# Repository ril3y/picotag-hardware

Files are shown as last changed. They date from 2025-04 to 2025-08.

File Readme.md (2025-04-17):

# PicoTag – Hardware Overview

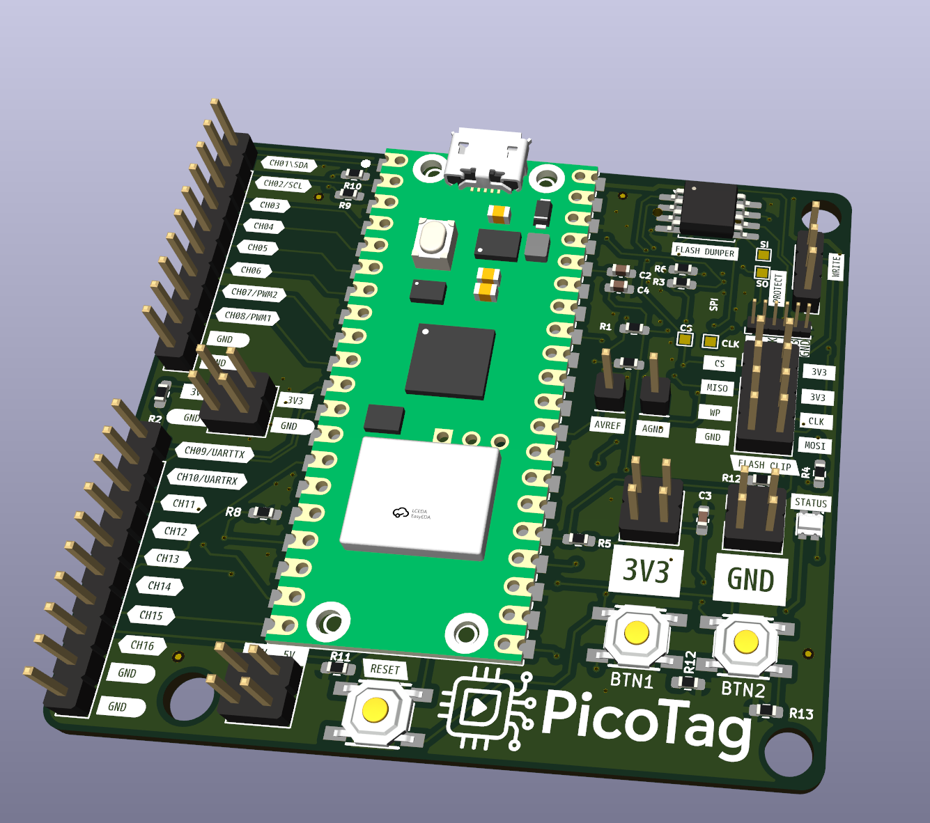
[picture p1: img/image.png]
PicoTag Hardware


**PicoTag** is a compact hardware reverse engineering and interface discovery board powered by the Raspberry Pi Pico W. It is designed for embedded developers and security researchers who need to scan, probe, and interact with unknown hardware interfaces like JTAG, SWD, SPI, and UART. The board routes 16 GPIOs for flexible digital analysis, integrates a flash dumper interface, and supports a built-in terminal experience via USB.

---

## 🧠 Core Features

- **Powered by Raspberry Pi Pico W (RP2040W)**
  - Dual-core ARM Cortex-M0+
  - USB-CDC console for interacting with the onboard terminal (SpicyTerm)
  - Wi-Fi ready for future remote applications

- **Runs PicoTag Terminal**
  - Interactive command-line terminal over USB serial
  - Extensible command modules (JTAG scan, Flash dump, GPIO monitor, etc.)

- **Supports Analog Inputs (3.3V only)**
  - Safely connect analog signals for measurement and analysis

---

## ⚙️ GPIO Scan Interface

- **16 dedicated GPIO channels** labeled `CH01` to `CH16`
  - Direct 3.3 V logic (no level shifting)
  - Clearly labeled edge connector for easy probing
  - CH01/02 double as I2C (SDA/SCL)
  - CH09/10 double as UART (TX/RX)
  - CH07/08 labeled for PWM

- **All GPIOs referenced to 3.3 V domain**
  - Designed for direct connection to 3.3 V targets
  - Ground and 3.3 V rails provided next to scan header for scope or logic analyzer use

---

## 🔌 Flash Dumper Interface

- **Dedicated SPI flash dump section**
  - Labeled `FLASH DUMPER` with headers for:
    - `CS`, `CLK`, `MISO`, `MOSI`, `WP`, `HOLD`
  - Designed for quick clip-to-dump workflows using SOIC-8 flash clips
  - Jumper-selectable voltage (3.3 V-only)
  - Status LED indicates active operations

---

## 🧠 Control & I/O

- **Two tactile buttons**: `BTN1` and `BTN2`
  - Used for scan triggers, reset functions, or user-defined inputs

- **RESET button** for the Pico W

- **Visuals and labeling**
  - High-quality silkscreen labels for every interface
  - Clean corner mounting holes and rounded PCB edges

---

## 🔋 Power Supply

- **USB-powered (5 V input via Pico W USB)**
- Onboard LDO provides 3.3 V (shared with all logic and headers)
- 3.3 V and GND pins broken out at multiple locations

---

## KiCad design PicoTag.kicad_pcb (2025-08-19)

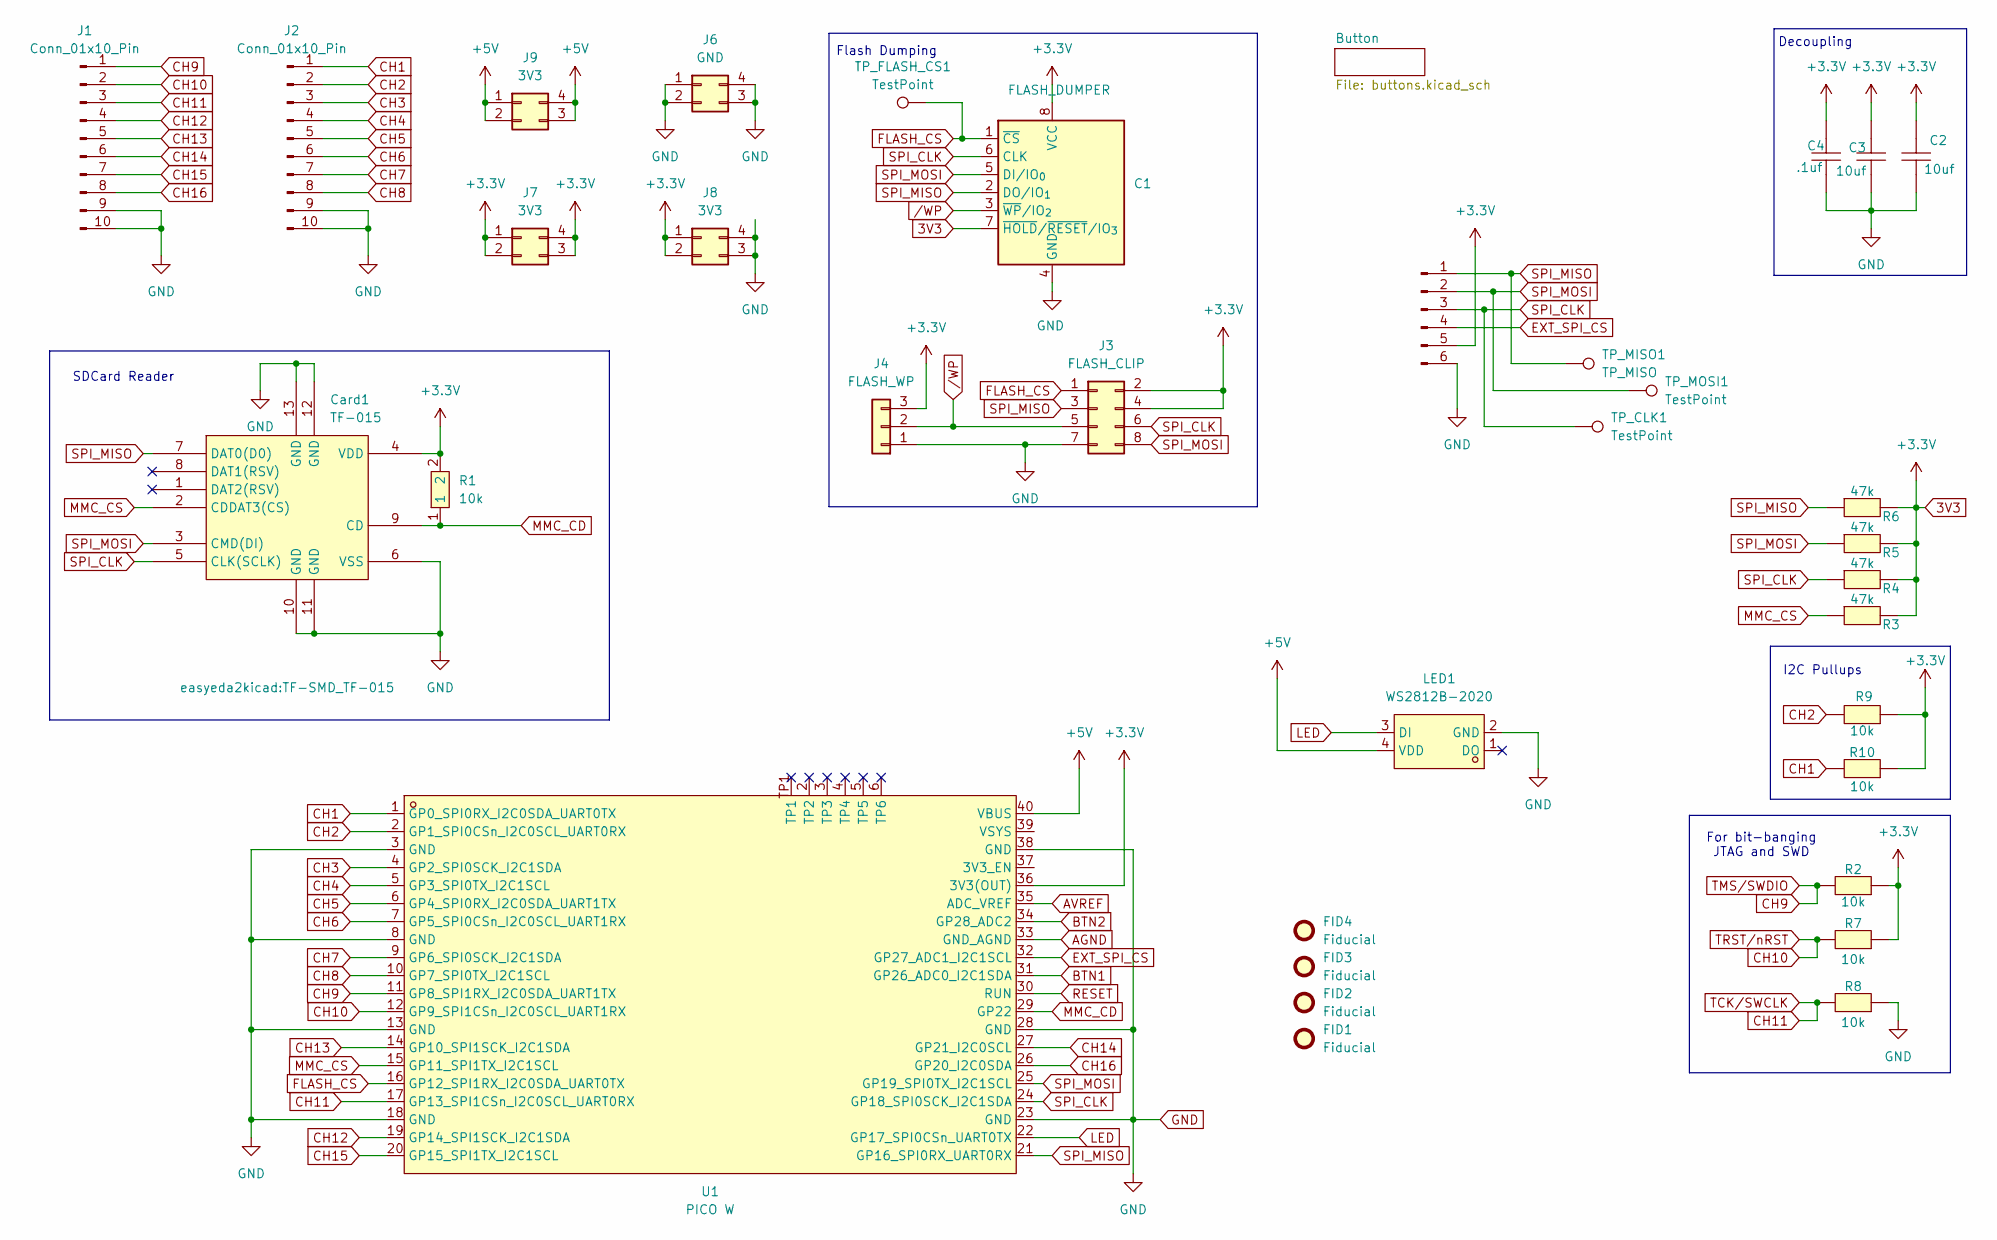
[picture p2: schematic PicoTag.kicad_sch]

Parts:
C1: FLASH_DUMPER; SOIC-8_5.3x5.3mm_P1.27mm flash dumper
C2, C3: 10uf; C_0603_1608Metric_Pad1.08x0.95mm_HandSolder; LCSC Part C1691
C4: .1uf; C_0603_1608Metric_Pad1.08x0.95mm_HandSolder; LCSC Part C1591
Card1: TF-015; TF-SMD_TF-015; LCSC Part C113206
FID1, FID2, FID3, FID4: Fiducial; Fiducial_0.5mm_Mask1mm
J1, J2: Conn_01x10_Pin; PinHeader_1x10_P2.54mm_Vertical
J3: FLASH_CLIP; PinHeader_2x04_P2.54mm_Vertical
J4: FLASH_WP; PinHeader_1x03_P2.54mm_Vertical
J6: GND; PinHeader_2x02_P2.54mm_Vertical
J7, J8, J9: 3V3; PinHeader_2x02_P2.54mm_Vertical
J11: Conn_01x06_Pin; PinHeader_1x06_P1.00mm_Vertical
LED1: WS2812B-2020; LED-SMD_4P-L2.0-W2.0-TL_WS2812B-2020; LCSC Part C965555
R1, R2, R7, R8, R9, R10: 10k; R_0603_1608Metric_Pad0.98x0.95mm_HandSolder; LCSC Part C2930027
R3, R4, R5, R6: 47k; R_0603_1608Metric_Pad0.98x0.95mm_HandSolder; LCSC Part C3016374
TP_CLK1: TestPoint; TestPoint_Pad_1.0x1.0mm
TP_FLASH_CS1: TestPoint; TestPoint_Pad_1.0x1.0mm
TP_MISO1: TP_MISO; TestPoint_Pad_1.0x1.0mm
TP_MOSI1: TestPoint; TestPoint_Pad_1.0x1.0mm
U1: PICO W; COMM-SMD_L51.0-W21.0-P2.54_PICOW; LCSC Part C7203003

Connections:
3V3: C1.7 (~HOLD/~RESET/IO_{3}), C1.8 (VCC), C2.2, C3.2, C4.2, Card1.4 (VDD), J3.2, J3.4, J4.3, J7.1, J7.2, J7.3, J7.4, J8.1, J8.2, J11.5, R1.2, R2.1, R3.2, R4.2, R5.2, R6.2, R7.1, R9.1, R10.1, U1.36 (3V3(OUT)); also elsewhere on the board
+5V: J9.1, J9.2, J9.3, J9.4, LED1.4 (VDD), U1.40 (VBUS)
AGND: U1.33 (GND_AGND)
AVREF: U1.35 (ADC_VREF)
BTN1: U1.31 (GP26_ADC0_I2C1SDA); also elsewhere on the board
BTN2: U1.34 (GP28_ADC2); also elsewhere on the board
CH1: J2.1, R10.2, U1.1 (GP0_SPI0RX_I2C0SDA_UART0TX)
CH2: J2.2, R9.2, U1.2 (GP1_SPI0CSn_I2C0SCL_UART0RX)
CH3: J2.3, U1.4 (GP2_SPI0SCK_I2C1SDA)
CH4: J2.4, U1.5 (GP3_SPI0TX_I2C1SCL)
CH5: J2.5, U1.6 (GP4_SPI0RX_I2C0SDA_UART1TX)
CH6: J2.6, U1.7 (GP5_SPI0CSn_I2C0SCL_UART1RX)
CH7: J2.7, U1.9 (GP6_SPI0SCK_I2C1SDA)
CH8: J2.8, U1.10 (GP7_SPI0TX_I2C1SCL)
CH9: J1.1, R2.2, U1.11 (GP8_SPI1RX_I2C0SDA_UART1TX)
CH10: J1.2, R7.2, U1.12 (GP9_SPI1CSn_I2C0SCL_UART1RX)
CH11: J1.3, R8.2, U1.17 (GP13_SPI1CSn_I2C0SCL_UART0RX)
CH12: J1.4, U1.19 (GP14_SPI1SCK_I2C1SDA)
CH13: J1.5, U1.14 (GP10_SPI1SCK_I2C1SDA)
CH14: J1.6, U1.27 (GP21_I2C0SCL)
CH15: J1.7, U1.20 (GP15_SPI1TX_I2C1SCL)
CH16: J1.8, U1.26 (GP20_I2C0SDA)
EXT_SPI_CS: J11.4, U1.32 (GP27_ADC1_I2C1SCL)
FLASH_CS: C1.1 (~CS), J3.1, TP_FLASH_CS1.1, U1.16 (GP12_SPI1RX_I2C0SDA_UART0TX)
GND: C1.4 (GND), C2.1, C3.1, C4.1, Card1.6 (VSS), Card1.10 (GND), Card1.11 (GND), Card1.12 (GND), Card1.13 (GND), J1.9, J1.10, J2.9, J2.10, J3.7, J4.1, J6.1, J6.2, J6.3, J6.4, J8.3, J8.4, J11.6, LED1.2 (GND), R8.1, U1.3 (GND), U1.8 (GND), U1.13 (GND), U1.18 (GND), U1.23 (GND), U1.28 (GND), U1.38 (GND); also elsewhere on the board
LED: LED1.3 (DI), U1.22 (GP17_SPI0CSn_UART0TX)
MMC_CD: Card1.9 (CD), R1.1, U1.29 (GP22)
MMC_CS: Card1.2 (CDDAT3(CS)), R3.1, U1.15 (GP11_SPI1TX_I2C1SCL)
RESET: U1.30 (RUN); also elsewhere on the board
SPI_CLK: C1.6 (CLK), Card1.5 (CLK(SCLK)), J3.6, J11.3, R4.1, TP_CLK1.1, U1.24 (GP18_SPI0SCK_I2C1SDA)
SPI_MISO: C1.2 (DO/IO_{1}), Card1.7 (DAT0(D0)), J3.3, J11.1, R6.1, TP_MISO1.1, U1.21 (GP16_SPI0RX_UART0RX)
SPI_MOSI: C1.5 (DI/IO_{0}), Card1.3 (CMD(DI)), J3.8, J11.2, R5.1, TP_MOSI1.1, U1.25 (GP19_SPI0TX_I2C1SCL)
/WP: C1.3 (~WP/IO_{2}), J3.5, J4.2

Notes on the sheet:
Flash Dumping
SDCard Reader
For bit-banging JTAG and SWD
Decoupling
I2C Pullups

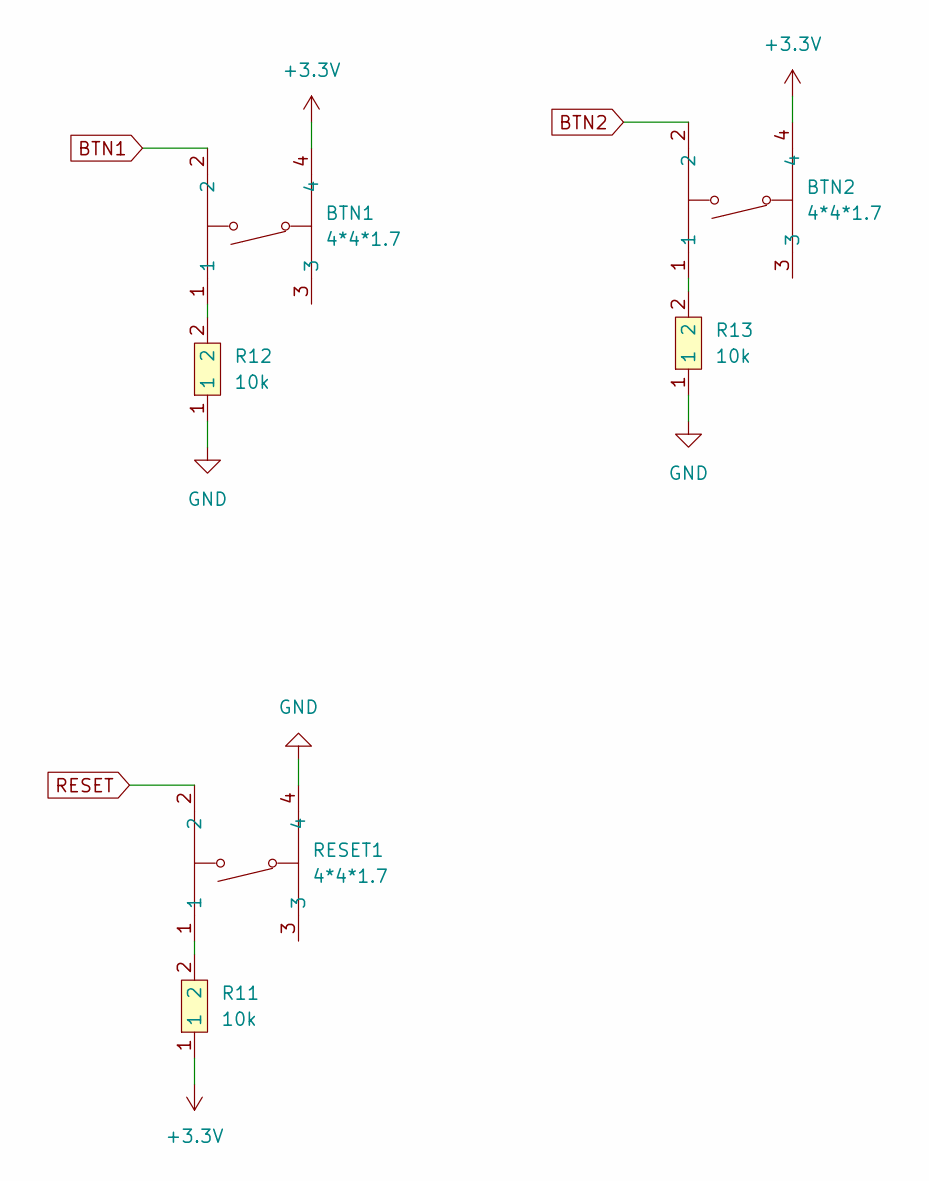
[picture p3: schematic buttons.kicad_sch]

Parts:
BTN1, BTN2: 4*4*1.7; SW-SMD_4P-L5.2-W5.2-P3.70-LS6.5; LCSC Part C10852
R11, R12, R13: 10k; R_0603_1608Metric_Pad0.98x0.95mm_HandSolder; LCSC Part C2930027
RESET1: 4*4*1.7; SW-SMD_4P-L5.2-W5.2-P3.70-LS6.5; LCSC Part C10852

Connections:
3V3: BTN1.4, BTN2.4, R11.1; also elsewhere on the board
BTN1: BTN1.2; also elsewhere on the board
BTN2: BTN2.2; also elsewhere on the board
GND: R12.1, R13.1, RESET1.4; also elsewhere on the board
unnamed: BTN1.1, R12.2
unnamed: BTN2.1, R13.2
unnamed: R11.2, RESET1.1
RESET: RESET1.2; also elsewhere on the board

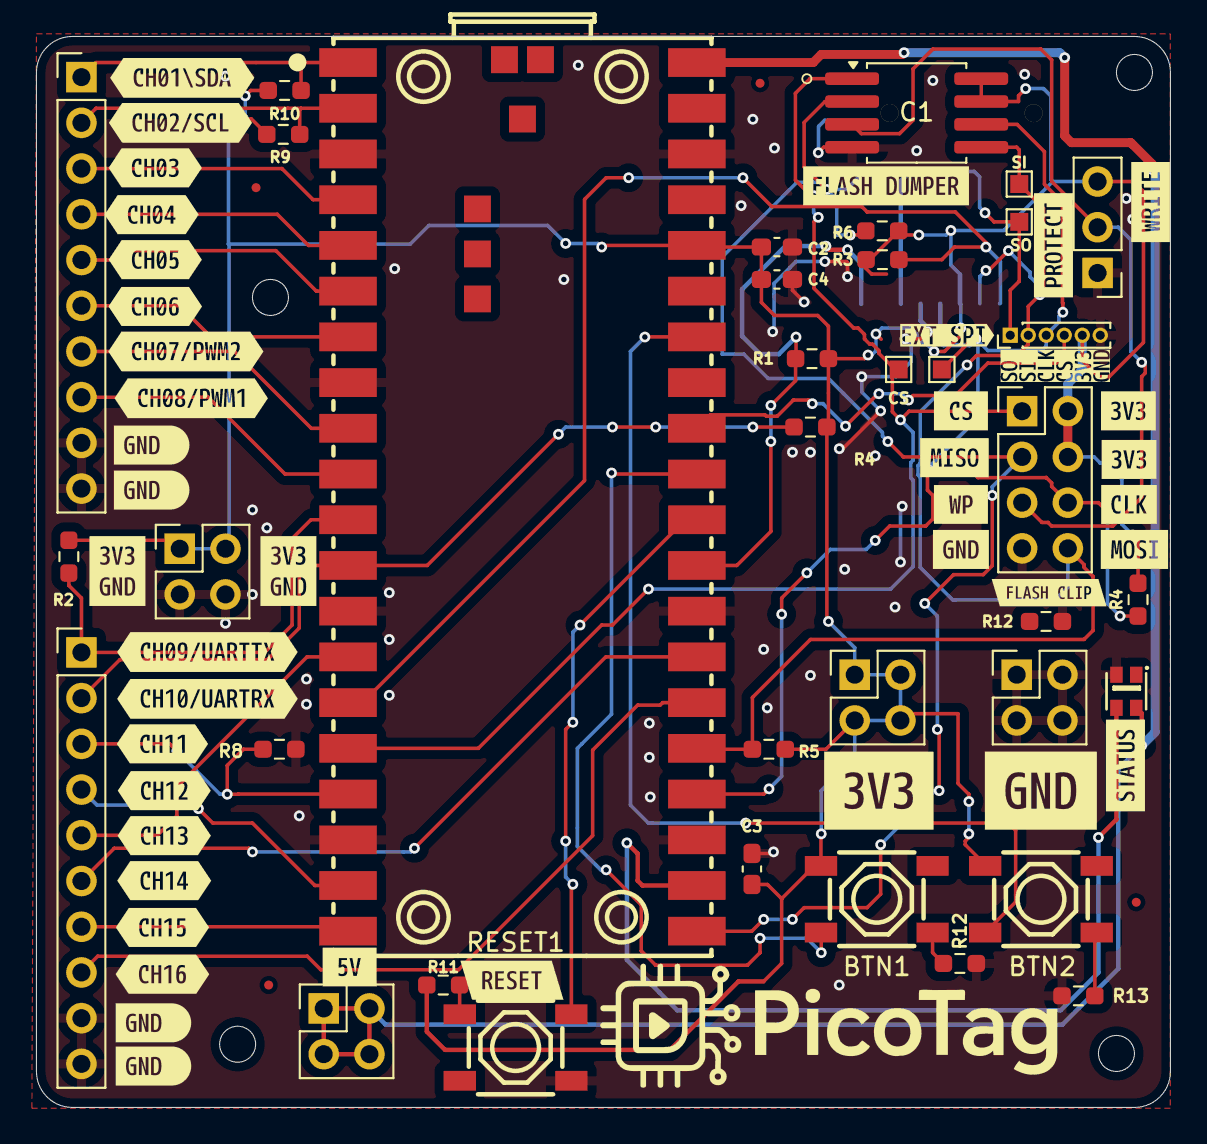
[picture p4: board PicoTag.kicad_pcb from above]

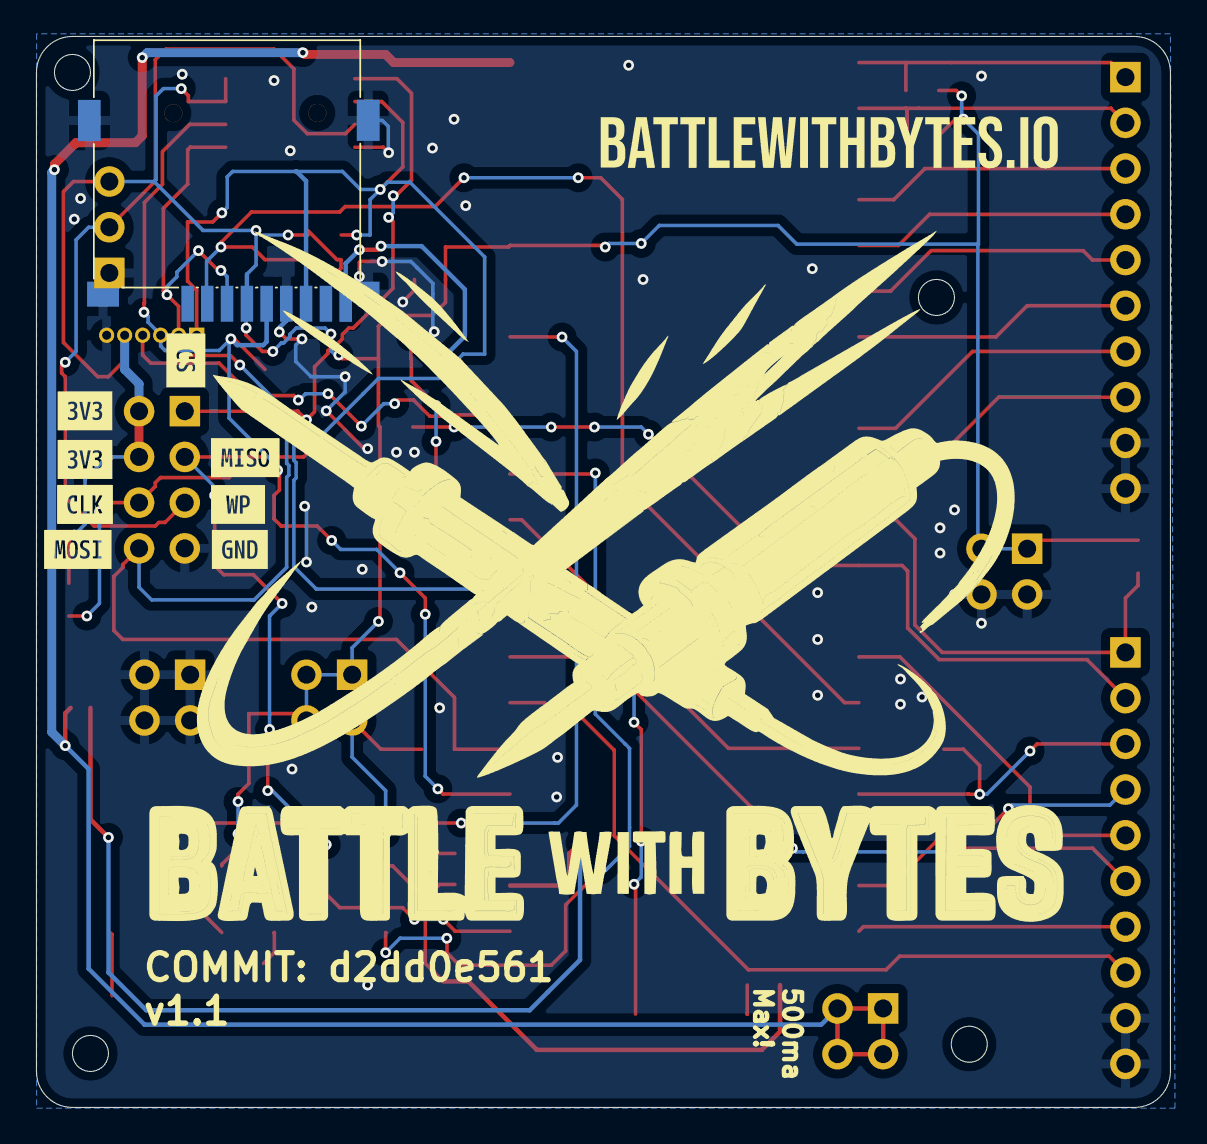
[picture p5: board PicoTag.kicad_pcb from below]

Board: 2 copper layers, 63.0 x 59.5 mm, 90 parts (9 on the bottom side), 34 nets.

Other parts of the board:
R12#2: 10k; R_0603_1608Metric_Pad0.98x0.95mm_HandSolder
kibuzzard-680A2A33: G***; kibuzzard-680A2A33
kibuzzard-680A2B2B: G***; kibuzzard-680A2B2B
kibuzzard-680A2B82: G***; kibuzzard-680A2B82
kibuzzard-680A26BF: G***; kibuzzard-680A26BF
kibuzzard-680A26E6: G***; kibuzzard-680A26E6
kibuzzard-680A26F2: G***; kibuzzard-680A26F2
kibuzzard-680A27E0, kibuzzard-680A27E0#2: G***; kibuzzard-680A27E0
kibuzzard-680A28B1: G***; kibuzzard-680A28B1
kibuzzard-680A28C8: G***; kibuzzard-680A28C8
kibuzzard-680A28D6: G***; kibuzzard-680A28D6
kibuzzard-680A28F0: G***; kibuzzard-680A28F0
kibuzzard-680A29B1: G***; kibuzzard-680A29B1
kibuzzard-680A29B9: G***; kibuzzard-680A29B9
kibuzzard-680A29C1: G***; kibuzzard-680A29C1
kibuzzard-680A29CB: G***; kibuzzard-680A29CB
kibuzzard-680A29D5: G***; kibuzzard-680A29D5
kibuzzard-680A29E5: G***; kibuzzard-680A29E5
kibuzzard-680A271C: G***; kibuzzard-680A271C
kibuzzard-680A273A: G***; kibuzzard-680A273A
kibuzzard-680A275A: G***; kibuzzard-680A275A
kibuzzard-680A280E: G***; kibuzzard-680A280E
kibuzzard-680A281D: G***; kibuzzard-680A281D
kibuzzard-680A282F, kibuzzard-680A282F#2: G***; kibuzzard-680A282F
kibuzzard-680A286D: G***; kibuzzard-680A286D
kibuzzard-680A291C: G***; kibuzzard-680A291C
kibuzzard-680A295C: G***; kibuzzard-680A295C
kibuzzard-680A296A: G***; kibuzzard-680A296A
kibuzzard-680A297B: G***; kibuzzard-680A297B
kibuzzard-680A2692: G***; kibuzzard-680A2692
kibuzzard-680A2725: G***; kibuzzard-680A2725
kibuzzard-680A2768, kibuzzard-680A2768#2, kibuzzard-680A2768#3: G***; kibuzzard-680A2768
kibuzzard-680A2774: G***; kibuzzard-680A2774
kibuzzard-680A2803: G***; kibuzzard-680A2803
kibuzzard-680A2843: G***; kibuzzard-680A2843
kibuzzard-680A2853: G***; kibuzzard-680A2853
kibuzzard-680A2862: G***; kibuzzard-680A2862
kibuzzard-680A2929: G***; kibuzzard-680A2929
kibuzzard-680A2935: G***; kibuzzard-680A2935
kibuzzard-680A2940: G***; kibuzzard-680A2940
kibuzzard-680A2949: G***; kibuzzard-680A2949
kibuzzard-680A2953: G***; kibuzzard-680A2953
kibuzzard-680A2987: G***; kibuzzard-680A2987
kibuzzard-68007E1C: G***; kibuzzard-68007E1C
kibuzzard-68007E04: G***; kibuzzard-68007E04
kibuzzard-68008EB3: G***; kibuzzard-68008EB3

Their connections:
GND: R12#2.1; also elsewhere on the board

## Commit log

2025-04-17 added hardware files
    [PicoTag-B_Cu.gbr, PicoTag-B_Mask.gbr, PicoTag-B_Paste.gbr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]
2025-04-17 hardware commit added
    [PicoTag.kicad_pcb]
2025-04-17 added version
    [PicoTag.kicad_pcb]
2025-04-24 Silkscreen fixes
    [PicoTag.kicad_pcb]
2025-08-19 Update hardware design files and generate manufacturing outputs
    - Updated PCB layout and schematic files
    - Regenerated gerber files for manufacturing
    - Added BOM and plot files
    [PicoTag-B_Cu.gbr, PicoTag-B_Mask.gbr, PicoTag-B_Paste.gbr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]
2025-08-19 Update hardware design and manufacturing files for version 1.1
    [PicoTag-B_Cu.gbr, PicoTag-B_Mask.gbr, PicoTag-B_Paste.gbr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]
